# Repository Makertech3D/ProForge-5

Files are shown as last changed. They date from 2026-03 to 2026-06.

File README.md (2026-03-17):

# ProForge 5 Tool Changer 3D Printer

ProForge 5 is an advanced, open-source, 5+ toolhead tool-changing 3D printer platform designed for high-speed, high-precision multi-material and multi-tool printing. This repository contains firmware config files, STL models for 3d printed parts and other documentation.

Available to order [here.](https://www.makertech3d.com/pages/proforge-5)

# Features
	•	Tool-Changing Mechanism: Swap up to 5 tools in a single print.
	•	Large Build Volume: 500mm(x) x 400mm(y) x 500mm(z).
  	• 	Print heads up to 300C. Bed up to 120C. Chamber up to 50C (at room temp).
	•	Multi-Material Compatibility: Support for PLA, ABS, PETG, flexible materials and others.
	•	Automated nozzle alignment and offset calibration.
	•	Rapid bed scanning and probing (tapping) via Eddy currrent probe.
	•	Klipper Firmware: High-speed and responsive motion control.
  	•	Geniuine Raspberry Pi 5 processor board and Bigtreetech Octopus Pro Control Board.
  	•	Premium component selection - Meanwell PSU, GATES belts, Stainless Steel rails and bearings.
  	•	Free standing design.

# ProForge 5 Klipper Firmware Image

The Klipper firmware image is available to download [here.](https://drive.google.com/file/d/1g3VlK6uW461eonK6xu36X5FfG2Ro1Mvd/view?usp=share_link)

# ProForge 5 Build Manual

The Official build guides for the ProForge 5 3D printer can be found [here](https://makertech-3d.dozuki.com/c/ProForge_5)

# Support and Community

If you run into any issues or need assistance with assembly or printing, feel free to ask for help in the official [Discord Server](https://discord.com/invite/FwgXFUw4R4)  or [Facebook Group](https://www.facebook.com/groups/proforge5).

If you’re missing a part or have received a faulty/broken one, please fill out [this form](https://www.makertech3d.com/missingpartform) for a replacement.

Want to get in touch? Drop us an email at info@makertech3d.com

# Safety Notice

Operate the ProForge 5 in a well ventilated, open and dry environment.

Be aware of the moving parts, there is a pinching hazard.

Be cautious of the Hotend, it can reach temperatures exceeding 300 degrees Celsius, this is hot enough to cause severe burns. Even after operation, the hotends can still be hot, allow time for them to cool before touching.

Keep children and pets away from the ProForge 5 whilst in operation.

Never disconnect any of the wiring whilst powered on.

Be careful of long hair and loose clothing when operating the ProForge 5.

Immediately shut down the ProForge 5 if an error occurs to prevent damage to the unit or its surroundings.

# Disclaimer

THIS PRODUCT IS A DO-IT-YOURSELF KIT TO BE ASSEMBLED BY THE USER AT THEIR OWN RISK. MAKERTECH 3D LTD DISCLAIMS ALL RESPONSIBILITY, RISK, OR LIABILITY OF ANY DAMAGE OR INJURY TO YOURSELF OR ANY PERSON OR PROPERTY FROM ITS USE.

NEITHER MAKERTECH 3D NOR ITS SUPPLIERS SHALL BE LIABLE TO YOU OR TO ANY THIRD PARTY FOR ANY INDIRECT, INCIDENTAL, CONSEQUENTIAL, SPECIAL, PUNITIVE, OR EXEMPLARY DAMAGES (INCLUDING IN EACH CASE, BUT NOT LIMITED TO, DAMAGES FOR THE INABILITY TO USE OR ACCESS THE PRODUCTS, LOSS OF DATA, LOSS OF BUSINESS, LOSS OF PROFITS, BUSINESS INTERRUPTION OR THE LIKE) ARISING OUT OF THE USE OF OR INABILITY TO USE THE PRODUCTS, EVEN IF MAKERTECH 3D HAS BEEN ADVISED OF THE POSSIBILITY OF SUCH DAMAGES.

MAKERTECH 3D IS NOT RESPONSIBLE FOR ANY PRODUCTS (3D PRINTED PARTS OR OTHER) PRODUCED WITH THE PROFORGE 5 OR ANY OF ITS OTHER PRODUCTS. IN NO EVENT SHALL MAKERTECH 3D BE LIABLE FOR ANY DAMAGE OR INJURY OCCURRED BY USING PRODUCTS PRODUCED BY THE PROFORGE 5 OR ANY OF ITS OTHER PRODUCTS.

NOTWITHSTANDING ANY DAMAGES THAT YOU MIGHT INCUR FOR ANY REASON WHATSOEVER (INCLUDING, WITHOUT LIMITATION, ALL DAMAGES REFERENCED HEREIN AND ALL DIRECT OR GENERAL DAMAGES IN CONTRACT OR ANYTHING ELSE), THE ENTIRE LIABILITY OF MAKERTECH 3D AND ANY OF ITS SUPPLIERS ARISING FROM OR RELATED TO THE USE OF THE PRODUCTS SHALL BE LIMITED TO THE AMOUNT ACTUALLY PAID BY YOU FOR THE PRODUCTS CONCERNED.

THE CUSTOMER IS FULLY AWARE OF THE TERMS OF USE MENTIONED IN THE ASSEMBLY MANUALS PROVIDED WITH THE PRODUCT AND AGREES WITH THESE TERMS OF USE WHEN ACCEPTING THE PRODUCT.

THE CUSTOMER HAS READ THE SAFETY INSTRUCTIONS PROVIDED IN THE MANUALS TO BUILD THE DIY-PRODUCTS OF MAKERTECH 3D. THE CUSTOMER ALSO AGREES IN FOLLOWING THESE SAFETY INSTRUCTIONS.

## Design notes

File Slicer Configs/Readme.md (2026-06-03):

# ProForge 5 — OrcaSlicer
[Click here.](https://github.com/Makertech3D/Orca-Slicer-Profiles)

# ProForge 5 — PrusaSlicer

This config bundle provides ready-to-use profiles for the ProForge 5 in PrusaSlicer, including printer settings, filament profiles, and start G-code optimised for the ProForge 5 toolchanger.

**Included profiles:**
- Printer: `ProForge 5`
- Print: `ProForge Default`
- Filaments: `PLA`, `ABS`

> **Note:** PrusaSlicer 2.9.4 or later is required.

---

## Importing the Config Bundle

1. Open PrusaSlicer
2. Go to **File → Import → Import Config Bundle...**
3. Navigate to and select `P5_PrusaSlicer_config_bundle.ini`
4. Click **Open** — the profiles will be imported automatically

---

## Selecting the Profiles

After importing, select the ProForge 5 profiles from the right-hand panel:

1. Set **Printer** to `ProForge 5`
2. Set **Print settings** to `ProForge Default`
3. Set **Filament** to your desired material (`PLA` or `ABS`)

---

## After Importing

- Go to **Printer Settings → General** and confirm the **Host** field shows the correct address for your ProForge 5 (default: `proforge5.local`)
- If you have updated your printer's hostname, update this field accordingly

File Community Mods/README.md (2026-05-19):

# 🛠️ ProForge 5 — Community Mods

Welcome to the official community mods folder for the **ProForge 5**! This is a curated collection of modifications, upgrades, and enhancements contributed by the community. Whether you're looking to improve print quality, expand capabilities, or add quality-of-life features, you'll find it here.

---

## 📋 Table of Contents

- [Getting Started](#getting-started)
- [Mod Categories](#mod-categories)
- [How to Submit a Mod](#how-to-submit-a-mod)
- [Mod Template](#mod-template)
- [Safety & Disclaimer](#safety--disclaimer)
- [Contributing Guidelines](#contributing-guidelines)
- [License](#license)

---

## Getting Started

Before installing any community mod, please make sure you have:

- Backed up your current printer configuration and settings
- Verified your firmware version is compatible with the mod
- Reviewed the mod's requirements and difficulty rating

> ⚠️ **Note:** Community mods are not officially supported by ProForge. Install at your own risk and always follow the safety guidelines below.

---

## Mod Categories

### 🖨️ Print Quality
Mods focused on improving layer adhesion, surface finish, accuracy, and overall output quality.

### ⚙️ Mechanical Upgrades
Hardware modifications including motion system improvements, frame bracing, vibration dampening, and component replacements.

### 🌡️ Thermal & Cooling
Hotend upgrades, part cooling enhancements, enclosure mods, and heated chamber improvements.

### 📦 Extruder & Feeder
Direct drive conversions, dual extrusion setups, filament sensor mounts, and runout detection mods.

### 🔌 Electronics & Wiring
Board replacements, cable management solutions, lighting, and power supply modifications.

### 💻 Software & Firmware
Custom firmware builds, slicer profiles, macros, and configuration files.

### 🗂️ Organization & Mounts
Tool holders, spool mounts, filament guides, camera mounts, and other utility accessories.

### 🎨 Cosmetic
Aesthetic mods, custom panels, logos, and visual upgrades.

---

## How to Submit a Mod

1. **Fork** this repository
2. Create a new folder under the relevant category using the naming convention:
   ```
   /community-mods/<category>/<your-mod-name>/
   ```
3. Include all required files (see [Mod Template](#mod-template) below)
4. Open a **Pull Request** with a clear title and description
5. Respond to any review feedback from maintainers

> Please ensure your mod has been personally tested on a ProForge 5 before submitting.

---

## Mod Template

Each mod submission **must** include the following structure:

```
your-mod-name/
├── README.md          # Description, instructions, photos
├── files/             # STL, CAD, config files, etc.
│   └── ...
├── images/            # Photos or renders of the mod
│   └── ...
└── CHANGELOG.md       # Version history (optional but encouraged)
```

### Required in your mod's `README.md`:

| Field | Description |
|---|---|
| **Author** | Your GitHub username |
| **Version** | e.g. `v1.0.0` |
| **Firmware Compatibility** | Tested firmware version(s) |
| **Difficulty** | Easy / Medium / Hard |
| **Print Time** | Estimated print time (if applicable) |
| **Materials Needed** | Hardware, filament type, tools |
| **Description** | What the mod does and why it's useful |
| **Installation Instructions** | Step-by-step guide |
| **Known Issues** | Any caveats or limitations |

---

## Safety & Disclaimer

- Always **power off** your printer before making hardware modifications
- **Community mods are not endorsed or tested by ProForge** — use them at your own risk
- Electrical modifications may **void your warranty** — proceed with caution
- Never leave a modified printer unattended during its first test print
- If a mod requires disabling safety features, consider the risks carefully

The maintainers of this repository are **not responsible** for any damage to your printer, property, or injury resulting from the use of community mods.

---

## Contributing Guidelines

To keep this repository clean and useful for everyone:

- ✅ Test your mod before submitting
- ✅ Use clear, descriptive names for files and folders
- ✅ Write instructions a beginner can follow
- ✅ Include photos or renders where possible
- ✅ Keep files reasonably sized (use releases for large assets)
- ❌ Do not submit mods that are untested or incomplete
- ❌ Do not plagiarise others' work without credit
- ❌ Do not include copyrighted material without permission

---

## License

Unless otherwise stated within an individual mod folder, all community contributions to this repository are shared under the **[Creative Commons Attribution 4.0 International (CC BY 4.0)](https://creativecommons.org/licenses/by/4.0/)** license.

You are free to share and adapt the material as long as appropriate credit is given.

---

## 🙌 Contributors

A huge thank you to everyone who has contributed mods, tested builds, and helped improve the ProForge 5 community!

---

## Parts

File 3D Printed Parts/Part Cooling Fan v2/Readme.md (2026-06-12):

# Part Cooling Fan v2.1

The new v2.1 part cooling fan shroud is a significant upgrade to the cooling system on your print head. Designed to wrap fully around the nozzle, it delivers **360° part cooling** for dramatically improved print quality, especially on overhangs, bridges, and fine details. 

The shroud is a 3D printed part, and it is recommended to be printed in ABS.

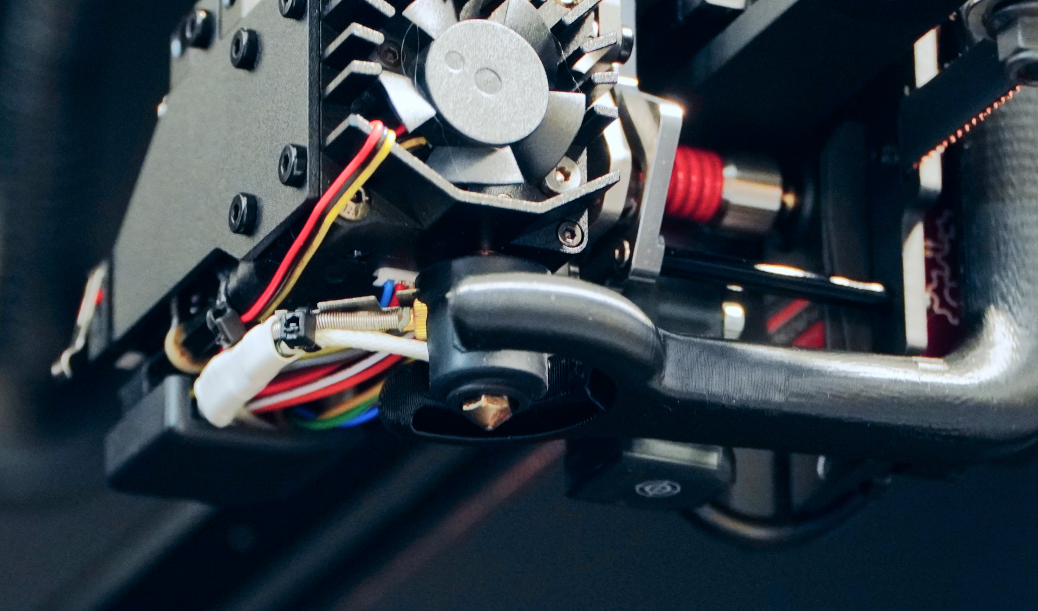
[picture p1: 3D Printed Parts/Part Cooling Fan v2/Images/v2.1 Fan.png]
Part Cooling Fan v2.1


---

## Installation

The fan shroud is secured using an **M4×12mm socket head bolt**, which replaces the existing M4×6mm bolt used to mount the servo. The longer bolt passes through both the fan shroud and the servo mounting point (lower left) simultaneously, clamping both components in a single fixing.

**Note:** 
After installation, re-run the `EDDY_CAL` macro to recalibrate the eddy current probe.

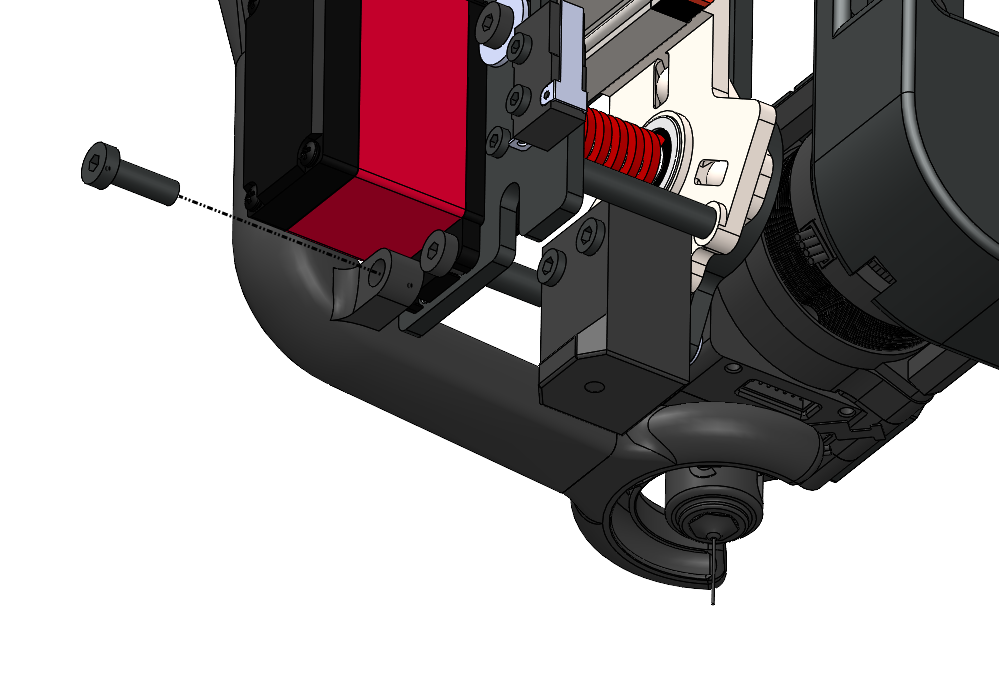
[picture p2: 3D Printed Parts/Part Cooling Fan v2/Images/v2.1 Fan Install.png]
Installation Diagram


**Hardware required:**
- 1× M4×12mm socket head bolt *(replaces the existing M4×6mm servo bolt)*

---

## Printing Instructions

The STL should be oriented in the slicer **exactly as shown** in the image below. Use **support from build plate only** and do not enable supports everywhere, as internal supports are difficult to remove and unnecessary with this orientation.

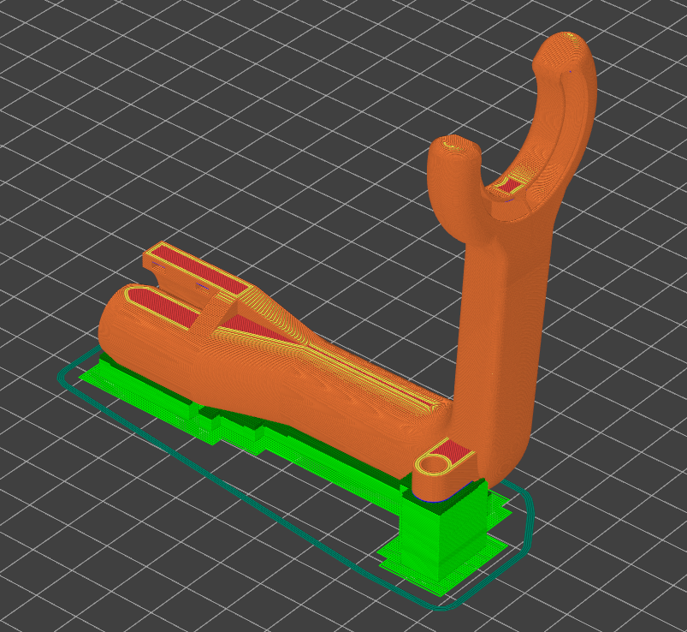
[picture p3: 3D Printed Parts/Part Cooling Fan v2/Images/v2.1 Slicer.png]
Slicer Orientation


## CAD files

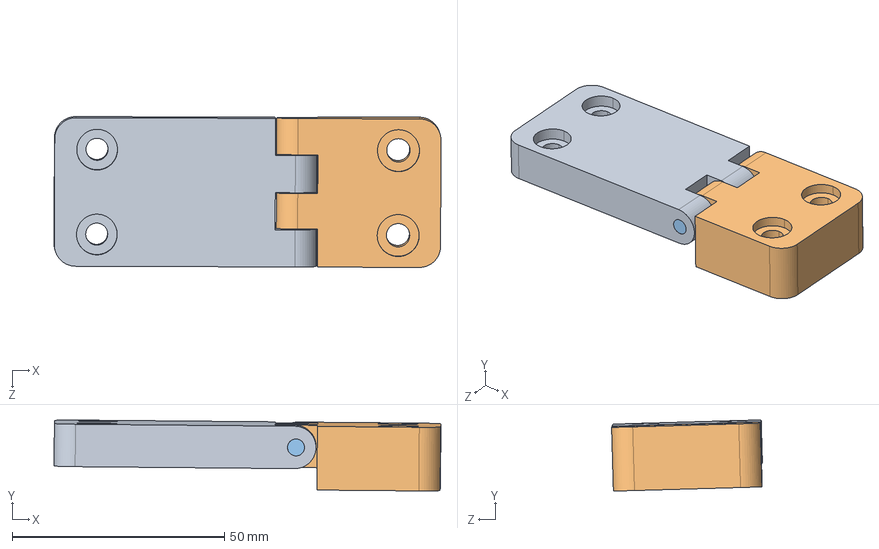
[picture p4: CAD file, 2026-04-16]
3D Printed Parts/Enclosure/P5 Door Hinge Assembly.STEP
91.2 x 16.7 x 35.6 mm
P5 Hinge B
P5 Hinge A
Hinge Pin

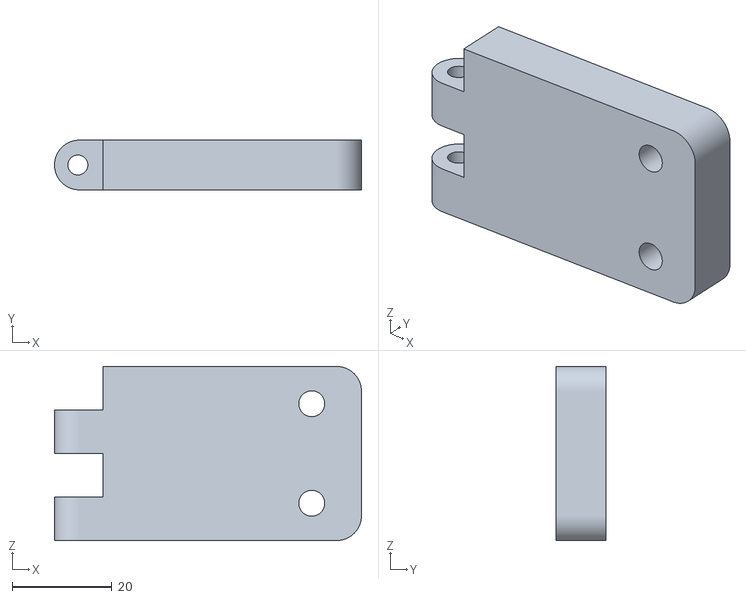
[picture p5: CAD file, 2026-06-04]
3D Printed Parts/Enclosure/P5 Hinge B.STL
61.7 x 10.0 x 35.0

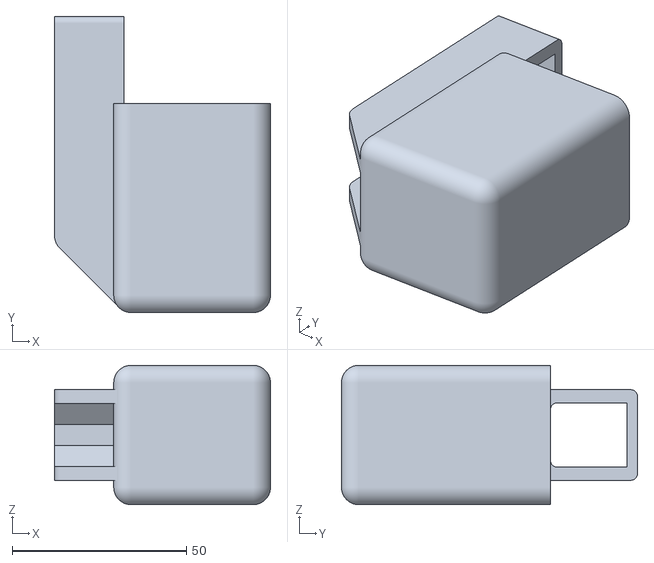
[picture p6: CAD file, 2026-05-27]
3D Printed Parts/P5_Ooze Bucket.STL
62.0 x 85.0 x 40.0

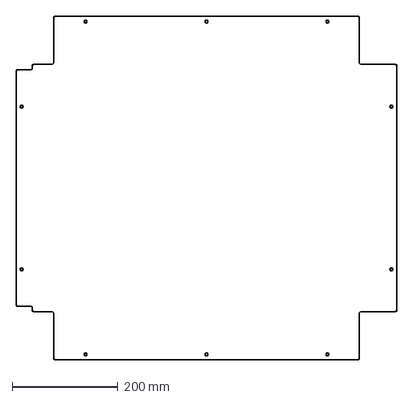
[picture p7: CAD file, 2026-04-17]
Enclosure Panels/P5 Bottom Panel.DXF
720.0 x 650.0 mm

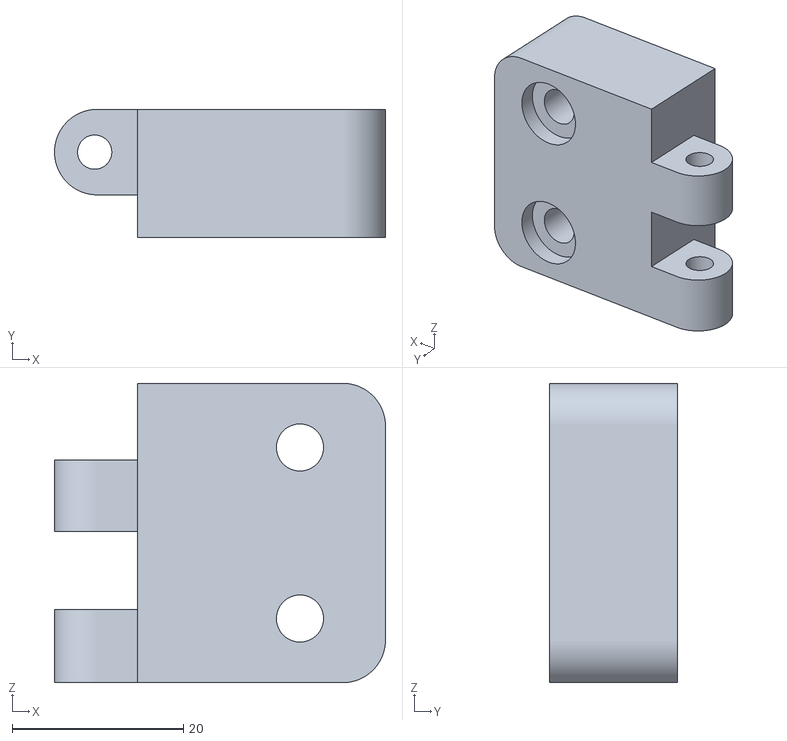
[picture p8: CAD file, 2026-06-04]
3D Printed Parts/Enclosure/P5 Hinge A.STL
38.7 x 15.0 x 35.0

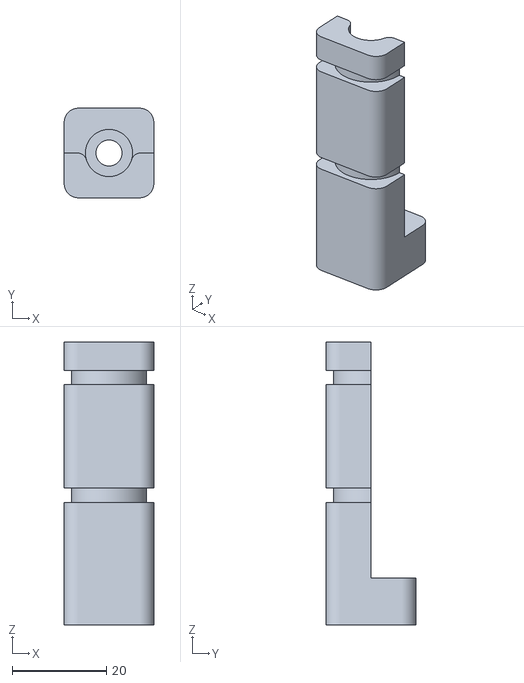
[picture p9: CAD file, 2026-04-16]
3D Printed Parts/P5 Platform Cable Relief Bracket.STL
19.0 x 19.0 x 60.0

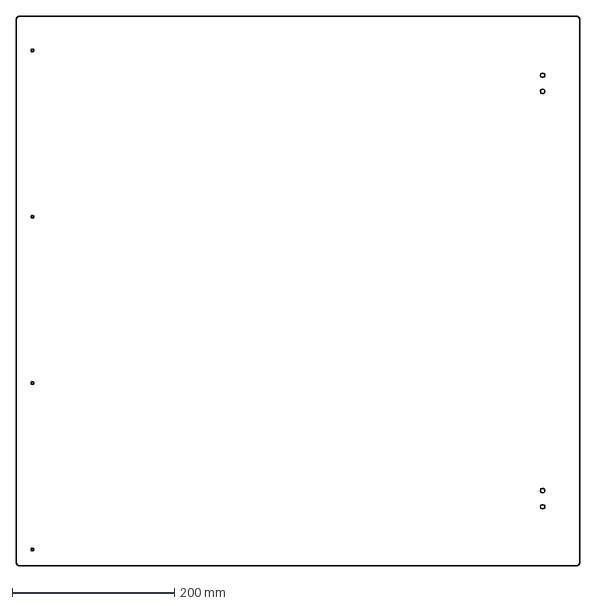
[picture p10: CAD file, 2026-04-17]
Enclosure Panels/P5 Front Lower Door.DXF
695.0 x 678.0 mm

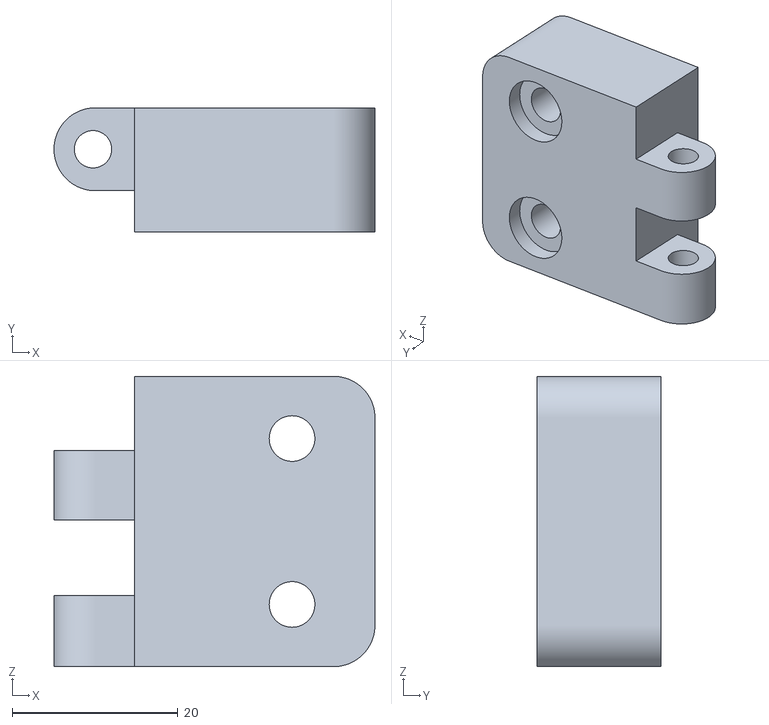
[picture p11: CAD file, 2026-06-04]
3D Printed Parts/Enclosure/P5 Hinge A (M4x30).STL
38.7 x 15.0 x 35.0

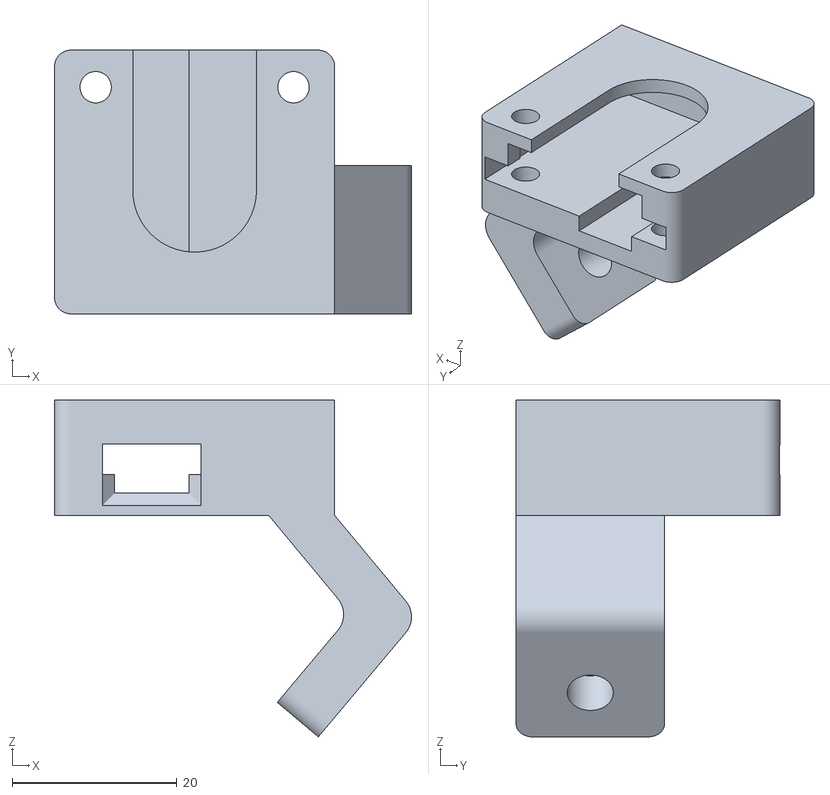
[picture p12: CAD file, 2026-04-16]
3D Printed Parts/P5_3D Printed Cam Case.STL
43.3 x 32.0 x 40.9

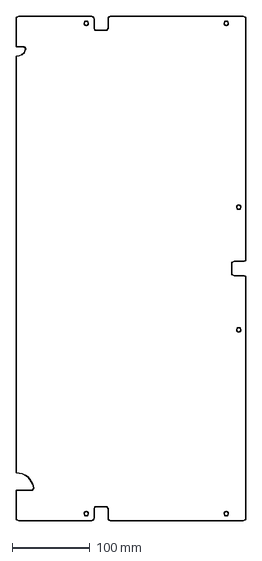
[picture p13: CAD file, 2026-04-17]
Enclosure Panels/P5 Left Lower Panel.DXF
295.0 x 648.0 mm

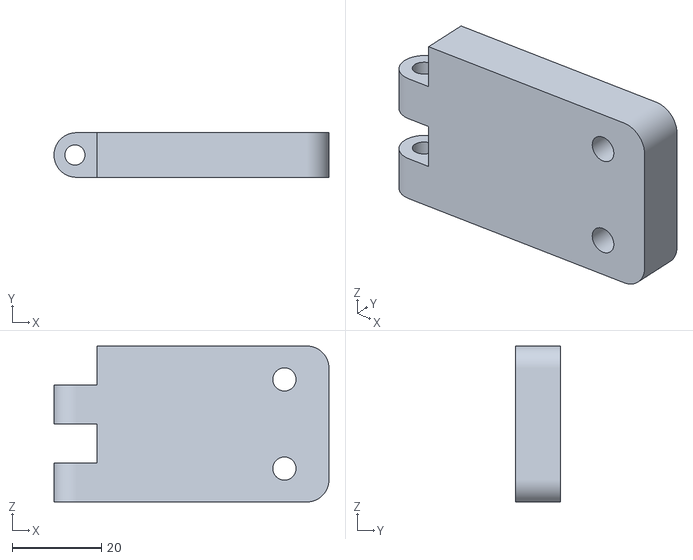
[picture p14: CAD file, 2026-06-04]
3D Printed Parts/Enclosure/P5 Hinge B (M4x30).STL
61.7 x 10.0 x 35.0

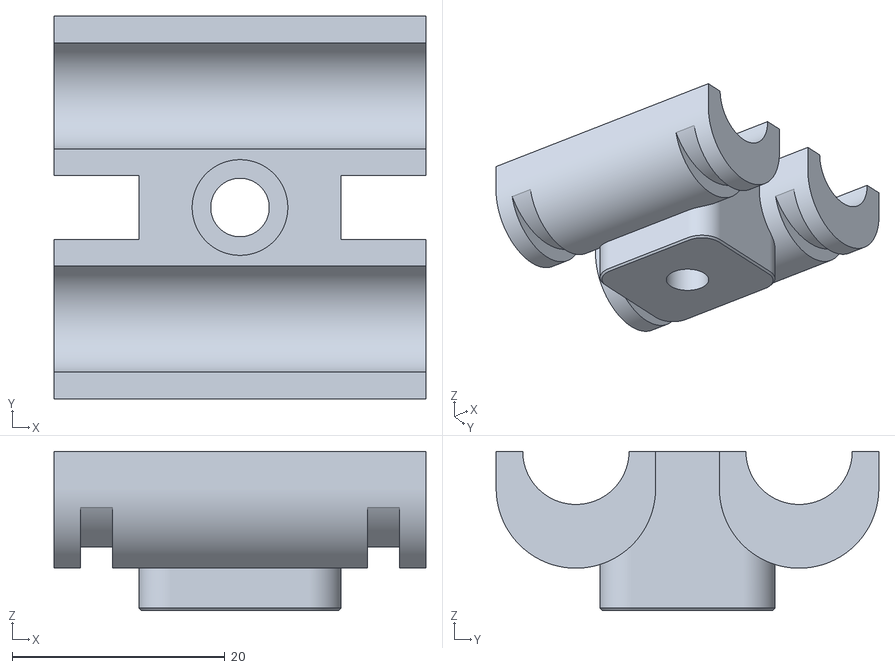
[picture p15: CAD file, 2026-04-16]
3D Printed Parts/P5 2-Channel Cable Guide.STL
35.0 x 36.0 x 15.0

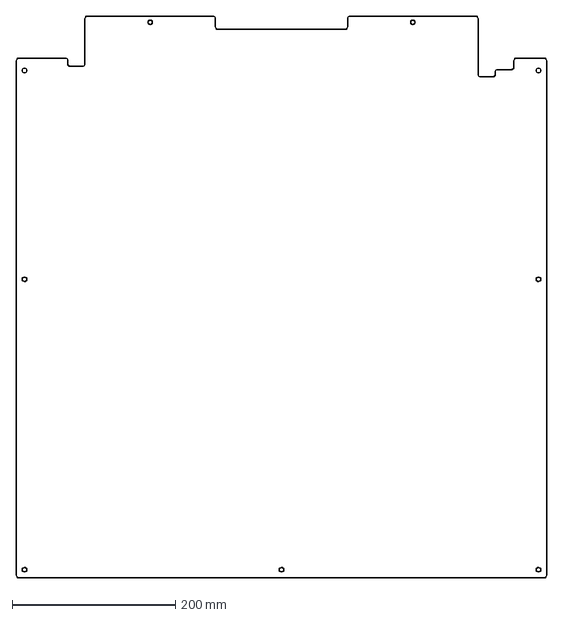
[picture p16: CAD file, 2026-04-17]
Enclosure Panels/P5 Right Lower Panel.DXF
650.0 x 688.5 mm

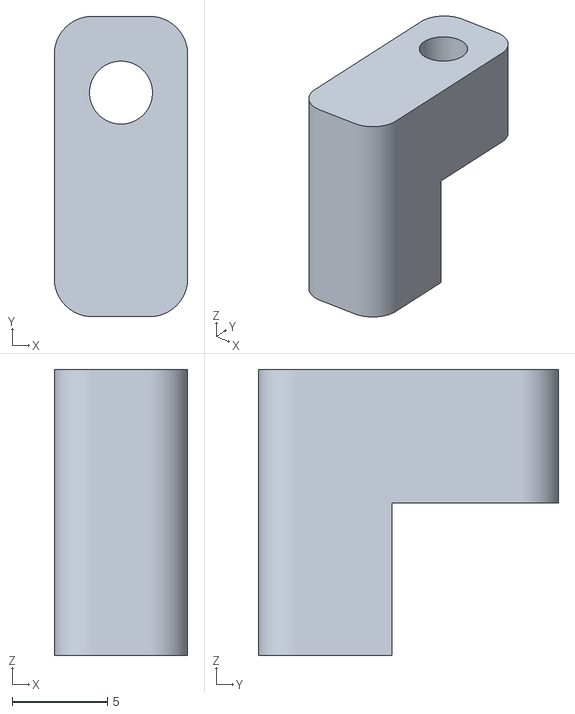
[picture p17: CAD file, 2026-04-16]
3D Printed Parts/P5 Display Bracket.STL
7.00 x 15.8 x 15.0

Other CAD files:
Enclosure Panels/P5 Top Panel.DXF
3D Printed Parts/Enclosure/P5 3D Printed Fume Filter - Pellet Tray.STL
3D Printed Parts/P5_ 3D Printed X-Endstop Mount.STL
Enclosure Panels/P5 Rear Upper Panel.DXF
3D Printed Parts/Enclosure/P5 3D Printer Fume Filter - Fan Shroud.STL
3D Printed Parts/Spool Holder Cover-1.STL
3D Printed Parts/Spool Holder Cover-2.STL
Enclosure Panels/P5 Front Upper Door.DXF
Enclosure Panels/P5 Left Upper Panel.DXF
Enclosure Panels/P5 Rear Lower Panel.DXF
Enclosure Panels/P5 Right Upper Panel.DXF

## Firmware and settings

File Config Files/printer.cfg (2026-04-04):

############################################################################
######################## ProForge 5 Printer Config #########################
############################################################################

#config file version v1.0.0
#release date: 17.03.2026

[include mainsail.cfg]
[include macros.cfg]
[include calibrate-offsets.cfg]

[include eddy.cfg]

#[include so3_0.cfg]
#[include so3_1.cfg]
#[include so3_2.cfg]
#[include so3_3.cfg]
#[include so3_4.cfg]

#[include enclosure.cfg]

[save_variables]
filename: ~/printer_data/config/variables.cfg
#   Required - provide a filename that would be used to save the
#   variables to disk e.g. ~/variables.cfg
[virtual_sdcard]
path: ~/printer_data/gcodes

[force_move]
enable_force_move: True

[mcu]
serial: /dev/serial/by-id/usb-Klipper_stm32h723xx_OctopusPro-if00

[exclude_object]

[printer]
kinematics: corexy
max_velocity: 500
max_accel: 20000
minimum_cruise_ratio: 0.6
square_corner_velocity: 8.0
max_z_velocity: 15
max_z_accel: 100

[gcode_arcs]
resolution: 0.1


# MOTOR-1
[stepper_x]
enable_pin: !PF14
step_pin: PF13
dir_pin: !PF12
rotation_distance: 40  # Adjust based on your lead screw or belt system
microsteps: 32
full_steps_per_rotation: 200  # Motor step angle: 1.8° = 200 steps per rotation
#gear_ratio: 1
#step_pulse_duration: 2  # Add if the driver requires a specific pulse width
endstop_pin: ^PG6
position_min: -120
position_endstop: 500
position_max: 500
homing_speed: 100  # mm/s; adjust for your mechanics
homing_retract_speed: 25  # mm/s
[tmc5160 stepper_x]
cs_pin: PC4
spi_bus: spi1
#spi_speed: 2000000
#spi_software_sclk_pin: PA5
#spi_software_mosi_pin: PA7
#spi_software_miso_pin: PA6
interpolate: True
run_current: 2.2  # Adjusted for 2.5A motor rating (approximately 85-90% for safety)
hold_current: 1.0  # Reduce for lower heat generation during idle
sense_resistor: 0.075
stealthchop_threshold: 0  # Disabled for better torque and stability on X-axis
# Driver Tuning
#driver_TBL: 1
#driver_TOFF: 3
#driver_PWM_OFS: 30
#driver_PWM_GRAD: 4
#driver_HSTRT: 7
#driver_HEND: 5



# MOTOR-2
[stepper_y]
enable_pin: !PF15
step_pin: PG0
dir_pin: !PG1
rotation_distance: 40  # Adjust based on your belt/pulley system
microsteps: 32
full_steps_per_rotation: 200  # Motor step angle: 1.8° = 200 steps per rotation
#gear_ratio: 1
#step_pulse_duration: 2  # Add if the driver requires a specific pulse width
endstop_pin: ^PG9
position_min: -20
position_endstop: 427
position_max: 427
homing_speed: 100  # mm/s; adjust if necessary for your mechanics
homing_retract_speed: 25  # mm/s
[tmc5160 stepper_y]
cs_pin: PD11
spi_bus: spi1
interpolate: True
run_current: 2.2  # Adjusted to ~85-90% of the motor's rated 2.5A for safe operation
hold_current: 1.0  # Reduced for less heat generation during idle
sense_resistor: 0.075
stealthchop_threshold: 0  # Disabled to keep torque consistent for the Y-axis
# Driver Tuning
#driver_TBL: 1
#driver_TOFF: 3
#driver_PWM_OFS: 30
#driver_PWM_GRAD: 4
#driver_HSTRT: 7
#driver_HEND: 5







# MOTOR-5 (Z0 Front Left)
[stepper_z]
enable_pin: !PG2
step_pin: PF9
dir_pin: !PF10
microsteps: 16
rotation_distance: 8
endstop_pin: probe:z_virtual_endstop
position_max: 500
position_min: -3.5
[tmc2209 stepper_z]
uart_pin: PF2
run_current: 1.1
sense_resistor: 0.11
stealthchop_threshold: 999999
interpolate: True           # Enables interpolation for smoother movement
hold_current: 0.4           # Sets a lower current when idle to reduce heat

# MOTOR-6 (Z1 Rear Left)
[stepper_z1]
enable_pin: !PF1
step_pin: PC13
dir_pin: !PF0
microsteps: 16
rotation_distance: 8
[tmc2209 stepper_z1]
uart_pin: PE4
run_current: 1.1
sense_resistor: 0.11
stealthchop_threshold: 999999
interpolate: True           # Enables interpolation for smoother movement
hold_current: 0.4           # Sets a lower current when idle to reduce heat

# MOTOR-7 (Z2 Rear Right)
[stepper_z2]
enable_pin: !PD4
step_pin: PE2
dir_pin: PE3
microsteps: 16
rotation_distance: 8
[tmc2209 stepper_z2]
uart_pin: PE1
run_current: 1.1
sense_resistor: 0.11
stealthchop_threshold: 999999
interpolate: True           # Enables interpolation for smoother movement
hold_current: 0.4           # Sets a lower current when idle to reduce heat

# MOTOR-8 (Z3 Front Right)
[stepper_z3]
enable_pin: !PE0
step_pin: PE6
dir_pin: PA14
microsteps: 16
rotation_distance: 8
[tmc2209 stepper_z3]
uart_pin: PD3
run_current: 1.1
sense_resistor: 0.11
stealthchop_threshold: 999999
interpolate: True           # Enables interpolation for smoother movement
hold_current: 0.4           # Sets a lower current when idle to reduce heat



[heater_bed]
heater_pin: PD15
sensor_type: Generic 3950
sensor_pin: PF3
control: pid
pid_Kp: 64.083
pid_Ki: 3.338
pid_Kd: 307.600
min_temp: 0
max_temp: 120

[fan]
pin: PB6                          # PWM Signal Pin
max_power: 0.9
hardware_pwm: True
cycle_time: 0.00004               # 25kHz
shutdown_speed: 0
kick_start_time: 0.2


[z_tilt]
z_positions:
 -60, -33.75
 -60, 476.25
 560, 476.25
 560, -33.75
points:
 3.8, 18.75
 3.8, 338.75
 423.8, 338.75
 423.8, 18.75
speed: 300
horizontal_move_z: 10
retries: 5
retry_tolerance: 0.5

[gcode_macro Z_TILT_ADJUST]
rename_existing: _Z_TILT_ADJUST
gcode:
    SAVE_GCODE_STATE NAME=STATE_Z_TILT
    BED_MESH_CLEAR
    {% if not printer.z_tilt.applied %}
    _Z_TILT_ADJUST horizontal_move_z=5 retry_tolerance=1
    {% endif %}
    _Z_TILT_ADJUST horizontal_move_z=2
    RESTORE_GCODE_STATE NAME=STATE_Z_TILT


[servo toolchanger]
pin: PE11
maximum_servo_angle: 180
minimum_pulse_width: 0.0005
maximum_pulse_width: 0.0025

[gcode_button carriage_tool_sensor]
pin: ^PG11
press_gcode:
release_gcode:

[respond]
default_type: echo

[neopixel Case_Light]
pin: PB10
chain_count: 48
color_order: RGB
initial_RED:   0.1   # dim red idle glow
initial_GREEN: 0
initial_BLUE:  0

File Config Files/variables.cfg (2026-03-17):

############################################################################
####################### ProForge 5 Variables Config ########################
############################################################################

#config file version v1.0.0
#release date: 17.03.2026

[Variables]
#Active Print Heads:
active_tools = 5

# Print Head SELECT Positions:

# Print Head 1:
zero_select_x = 0
zero_select_y = 0

# Print Head 2:
one_select_x = 0
one_select_y = 0

# Print Head 3:
two_select_x = 0
two_select_y = 0

# Print Head 4:
three_select_x = 0
three_select_y = 0

# Print Head 5:
four_select_x = 0
four_select_y = 0


# Print Head DOCKING Positions:

# Print Head 1:
zero_dock_x = 0
zero_dock_y = 0

# Print Head 2:
one_dock_x = 0
one_dock_y = 0

# Print Head 3:
two_dock_x = 0
two_dock_y = 0

# Print Head 4:
three_dock_x = 0
three_dock_y = 0

# Print Head 5:
four_dock_x = 0
four_dock_y = 0





# Print Head X/Y Offsets:

# Print Head 1: 
# (0,0,0) - reference position

# Print Head 2 Offset:
one_x_offset = 0
one_y_offset = 0
one_z_offset = 0

# Print Head 3 Offset:
two_x_offset = 0
two_y_offset = 0
two_z_offset = 0

# Print Head 4 Offset:
three_x_offset = 0
three_y_offset = 0
three_z_offset = 0

# Print Head 5 Offset:
four_x_offset = 0
four_y_offset = 0
four_z_offset = 0

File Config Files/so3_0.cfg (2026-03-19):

############################################################################
##################### SmartOrbiter v3 - Print Head 0 #######################
############################################################################

#config file version v1.3.0
#release date: 06.06.2025

[mcu so3_0]
serial: /dev/serial/by-id/usb-Klipper_stm32f042x6_PH1-if00



#################################################################################################################
################################ CHANGE HERE MACRO CONFIGURABLES ################################################
#################################################################################################################

[gcode_macro _SENSOR_VARIABLES_0]         # change here macro configurables, enable disable functions!*************************
variable_filament_load_temp     :220    # temperature to heat up hotend for filament loading, default is 235
variable_filament_unload_temp   :185    # temperature to heat up hotend for filament un-loading, default is 185
variable_filament_load_min_temp :190    # minimum hotend set temperature allowed in filament load macro, default is 190
variable_nozzle_purge_length    :100    # filament extrude amount during load sequenc, hotend purge from old filament, default is 100
variable_nozzle_purge_speed     :300    # filament extrude speed in mm/min adjust this value lower if flow is too high and extruder skips during loading, default is 300
variable_disable_autoload       :False  # disable filament autoload feature by setting this variable True
variable_disable_runnout        :False  # disable runnout by setting this variable True
variable_disable_autounload     :False  # disable auto unload filament by setting this variable to True
variable_enable_beep            :False   # uses M300 sound feature, set it True to enable
variable_SENSOR_RGB_LED         :False  # enable and configure RGB LED pin and type for filament status indication
variable_park_position_x        :100    # edit your X parking position here for pause macro trigerred by runnout
variable_park_position_y        :10     # edit your Y parking position here for pause macro trigerred by runnout
variable_park_lift_z            :10     # edit your Z lift amount for parking position here, default is 10
variable_park_retraction        :1      # edit your retraction amount for parking, default is 1
gcode:


##################################################################
########################## EXTRUDER ##############################
##################################################################
[extruder]
step_pin: so3_0:PB7
dir_pin: so3_0:PB6
enable_pin: !so3_0:PB4
microsteps: 32
full_steps_per_rotation: 200
#rotation_distance = <full_steps_per_rotation> * <microsteps> / <steps_per_mm>
rotation_distance: 4.69
nozzle_diameter: 0.400
filament_diameter: 1.750
max_extrude_only_distance: 2500
max_extrude_only_velocity: 120
max_extrude_only_accel: 3000
heater_pin: so3_0:PA0
sensor_type: ATC Semitec 104NT-4-R025H42G  
sensor_pin: so3_0:PA2
pullup_resistor: 4700
min_temp: 0
max_temp: 300
pressure_advance: 0.03 
pressure_advance_smooth_time: 0.02
min_extrude_temp: 165
smooth_time: 0.5
max_extrude_cross_section:10
max_power: 0.995
pwm_cycle_time: 0.01
control = pid
#Default SO3 PID Values:
pid_Kp=24.859 
pid_Ki=2.072 
pid_Kd=74.578
#REVO SO3 PID Values:
#pid_Kp=23.445
#pid_Ki=1.839
#pid_Kd=74.733
[tmc2209 extruder] 
uart_pin: so3_0:PB5
#uart_address: 3 # comment out this line in case UART address definition is not required
interpolate: true
run_current: 0.80
sense_resistor: 0.11
stealthchop_threshold: 0

[heater_fan Hotend0_Fan]
pin: !so3_0:PA8
tachometer_pin: so3_0:PA3
tachometer_ppr: 2
tachometer_poll_interval: 0.0005
heater: extruder
cycle_time: 0.0001 #10KHz PWM frecvency
#cycle_time: 0.01 #100Hz PWM frecvency
heater_temp: 75
fan_speed: 0.65
hardware_pwm: false
shutdown_speed: 0.0
max_power: 1.0


#################################################################################################################################
####################################### DO NOT CHANGE ANYTHING BELOW THIS LINE!!! ###############################################
#################################################################################################################################
####################################### UNLESS YOU KNOW WHAT YOU ARE DOING OR YOU ARE BORED AND NEED TO DO SOMETHING OR YOU ARE ALONE AND NEED SOMETHING TO MESS UP YOUR LIFE OR YOU CAN DO IT BETTER THAN ME OR YOU ARE A REAL SMARTASS OR JUST BECAUSE YOU CAN OR YOU RUN OUT OF BEAR OR HAS NOTHING BETTER TO DO OR ANY UNREASONABLE REASON
#################################################################################################################################

[respond]
default_type: echo

[force_move]
enable_force_move: True

#################################################################################################################################
########################################### so3_0 Features Configuration ##########################################################
#################################################################################################################################

[neopixel SO3RGB_0]
pin: so3_0:PB8
chain_count: 1
color_order: GRB
initial_RED: 0.5
initial_GREEN: 0.5
initial_BLUE: 0.5

[thermistor so3_0Thermistor]
temperature1: 25
resistance1: 100000
beta: 3950

[temperature_sensor so3_0]
sensor_type: so3_0Thermistor
sensor_pin: so3_0:PB1
pullup_resistor: 4700
min_temp: 0
max_temp: 85

[output_pin HOT_LED]
pin: so3_0:PA9
value: 1
shutdown_value: 0

[lis2dw]
cs_pin: so3_0:PA4
spi_bus: spi1
axes_map: y, z, x

[resonance_tester]
accel_chip: lis2dw
probe_points: 150,150,30  # edit XYZ head position for testing
min_freq: 10
max_freq: 200

[gcode_button t0_dock_sensor]
pin: ^so3_0:PB0
press_gcode:
release_gcode:

#################################################################################################################################
############################################## Runout and autoload macros #######################################################
#################################################################################################################################

#################################################################################################################################
####################################### DO NOT CHANGE ANYTHING BELOW THIS LINE!!! ###############################################
#################################################################################################################################
####################################### UNLESS YOU KNOW WHAT YOU ARE DOING OR YOU ARE BORED AND NEED TO DO SOMETHING OR YOU ARE ALONE AND NEED SOMETHING TO MESS UP YOUR LIFE OR YOU CAN DO IT BETTER THAN ME OR YOU ARE A REAL SMARTASS OR JUST BECAUSE YOU CAN OR YOU RUN OUT OF BEAR OR HAS NOTHING BETTER TO DO OR ANY UNREASONABLE REASON
#################################################################################################################################


#*****************************initial RGB LED set at printer start****************************************************************
[delayed_gcode startup_RGB_SET_0]
initial_duration: 2
gcode:    
  {% if printer["filament_switch_sensor SO3Sensor_0"].filament_detected==true %}
      SET_LED LED=SO3RGB_0 RED=0.0 GREEN=1.0 BLUE=0.0
  {% else %}
      SET_LED LED=SO3RGB_0 RED=1.0 GREEN=0.0 BLUE=0.0
  {% endif %}   


#***********************************filament swicth definition***********************************************************

[filament_switch_sensor SO3Sensor_0]
switch_pin: so3_0:PA13
pause_on_runout: False # do not change to true, printer is paused in the next sections
runout_gcode: UPDATE_DELAYED_GCODE ID=runnout_filter_0 DURATION=0.5 # duration defines the filter time for runnout detection
insert_gcode: _filament_load_init_0
event_delay: 1.0
pause_delay: 0.1


#////////////////////////////////////////Filament Unload macros/////////////////////////////////////////////////

[gcode_button _filament_unload_0]
pin: !so3_0:PA10
release_gcode:  # filament unload procedure   
  SET_LED LED=SO3RGB_0 RED=0.0 GREEN=0.5 BLUE=0.5
  _filament_unload_init_0
press_gcode: # do not add any macro call here

[delayed_gcode runnout_filter_0]
gcode: #checking if filament runout is still present after defined delay time, default 0.5s
  {% if printer["filament_switch_sensor SO3Sensor_0"].filament_detected==false %}
      _runnout_init_0
  {% else %}
      M118 Runnout sensor_0 intermitent contact detected!
  {% endif %}
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

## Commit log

2026-03-17 ProForge 5 Config Files v1.0.0 (IR)
    [calibrate-offsets.cfg, eddy.cfg, enclosure.cfg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]
2026-03-19 Bug fixes and clean up
    [macros.cfg, so3_0.cfg]
2026-03-20 Bug fix
    [macros.cfg]
2026-03-25 3D Printed Parts
    [Spool Holder Cover-1.STL, Spool Holder Cover-2.STL]
2026-04-04 removed test save_config
    [printer.cfg]
2026-04-16 ProForge 5 3D Printed Parts
    ProForge 5 3D Printed Parts
    [P5 2-Channel Cable Guide.STL, P5 3D Printed Fume Filter - Pellet Tray.STL, P5 3D Printer Fume Filter - Fan Shroud.STL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]
2026-04-17 Enclosure Panel DXF's
    Enclosure Panel DXF's
    [P5 Bottom Panel.DXF, P5 Front Lower Door.DXF, P5 Front Upper Door.DXF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]
2026-05-27 Updated Fan Shroud and Ooze Bucket
    [P5_Ooze Bucket.STL]
2026-05-28 Update Eddy.cfg - v1.0.1
    Added tap_target_z: -0.35
    [eddy.cfg]
2026-05-28 Macros.cfg Update - v1.1.0
    Prime and Wipe macros and bug fixes.
    [macros.cfg]
2026-06-03 Part Cooling Fan Shroud v2
2026-06-04 3D Printed Parts Update
    [P5 3D Printed Fume Filter - Pellet Tray.STL, P5 3D Printer Fume Filter - Fan Shroud.STL, P5 Door Hinge Assembly.STEP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]
2026-06-12 Fan Shroud v2.1 Update
2026-10-06 Create P5 - REVO Print Head Cover.STL
2026-10-12 v1.4.0 bug fix: false filament runout pauses
    Fixes false runout pauses and motion stalls caused by brief filament switch dropouts on all five tool configs.
    Runout detection now polls the switch and only pauses after 3 seconds of continuous no contact. The old runout_gcode handler is removed, so Klipper no longer stops the toolhead on every dropout.
    Tested with simulated runouts, reload and resume working as before.
2026-10-22 Print Head Covers
